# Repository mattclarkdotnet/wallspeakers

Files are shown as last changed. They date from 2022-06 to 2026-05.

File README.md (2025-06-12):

# wallspeakers

Depth 46mm (as flat as the TV)
Max continuous output 95dB @ >80Hz, 85dB @50Hz (suitable for small room use)
IDD ~ 50mm (minimal lobing at crossover where 1/4 wavelength is ~200mm)
Crossover ~400Hz (avoids BMR distortion below that)
Wide dispersion & low IDD mean even tonality vertically and horizontally for wide or no sweet spot

## construction

The interior depth is set to be exactly the mounting depth of the bass driver less the thickness of the rebate, so the magnet would just touch the back wall if there was no gasket between the driver flange and the rebate.  When mounting, apply a layer of gasket material to the rear of the bass driver as well as to the rebate.

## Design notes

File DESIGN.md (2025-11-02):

The world’s slimmest and most advanced on-wall loudspeaker.
- [ ] Just 50mm deep for discreet wall mounting
- [ ] Sleek design to match all rooms
- [ ] Machined from aluminium for ultimate strength and sound quality in a small package
- [ ] Direct driver control with room correction and listening position optimisation
- [ ] Accurate sound anywhere in the room
- [ ] Suitable as a centre speaker or a stereo pair or both
- [ ] Stereo audio from TV (analog or digital)
- [ ] App for control and customisation
- [ ] IR learning of TV volume
- [ ] Matching control box and remote
- [ ] Expandable with extra speakers and subwoofers
- [ ] Optional grille
- [ ] Custom colours

For later designs:
- [ ] HDMI ARC/eARC audio input
- [ ] HDMI control of volume

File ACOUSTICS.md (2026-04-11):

* 2 x Dayton LW150-4 woofers (86dB/2.83V, Re=3.6, parallel Re=1.8)
* 1 x Tectonic TEBM28C10 (80dB/2.83V, Re=3.9)
* 500x200x48mm aluminium cabinet
* 400Hz crossover

### Driver sensitivity matching

The two woofers have a combined sensitivity (being closely spaced and seeing the same signal) of 86+6=92dB/2.83V, at the cost of a reduced Re of 1.8.

Therefore at the crossover frequency the woofer level needs to be reduced by 12dBSPL, or 24dBV

However a Linkwitz Transform is applied to the woofer, which has a 10dBV gain.  We will likely also want to apply up to 10dB of loudness compensation and/or room correction for low level listening to the bass region.  Therefore the 24dBV drop at the crossover region will work out well to provide the needed bass headroom.

### Driver power handling

The woofers have a Linkwitz transform applied to move f3 to 54Hz and f6 to 42Hz.

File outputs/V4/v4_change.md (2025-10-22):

* change total depth to 48mm (proto 1 was designed to be 50mm but ended at 43mm due to machining issue)
* increased the rim lip depth from 5 to 5.5mm to allow for use of glued-on 0.8mm rubber gasket material on back plate
* increased from 3 to 4 screw posts per side, with nominal 14mm post diameter
* moved the BMR driver 5mm inboard (so hole centre is now 45mm from midline, down from 50mm before)
* added machined subenclosure woth optimised shape to address resonance issues
* combined the machined subenclosure and its screw posts
* Reduced woofer support ring diameter (168->160)
* increased BMR support ring diameter (65->66)
* removed dress-up detail on the main shell interior that wasn't structural
  * kept the fillet around the edges to match the exterior roundover, as this is structurally important
  * left all other fillets and chamfers on the interior to  the machinists discretion

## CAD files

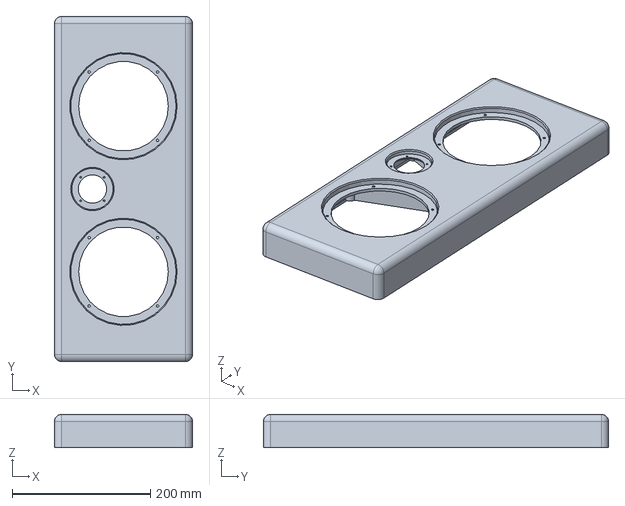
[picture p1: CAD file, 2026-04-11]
cad_models/wallspeakers prototype v5-main shell.step
200.0 x 500.0 x 48.0 mm

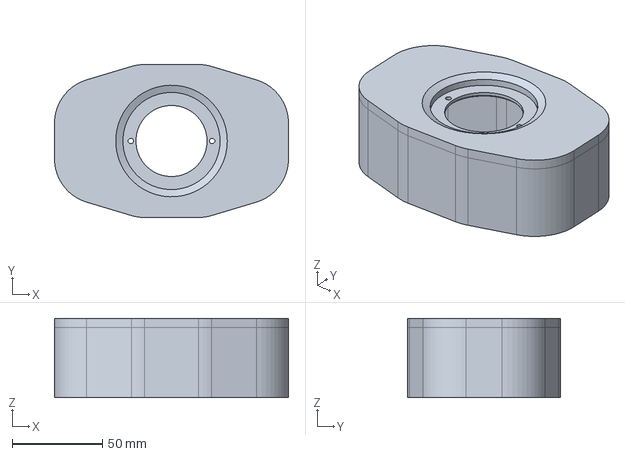
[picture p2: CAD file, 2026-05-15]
cad_models/mule v8.0.FCStd
130.0 x 85.0 x 44.1 mm

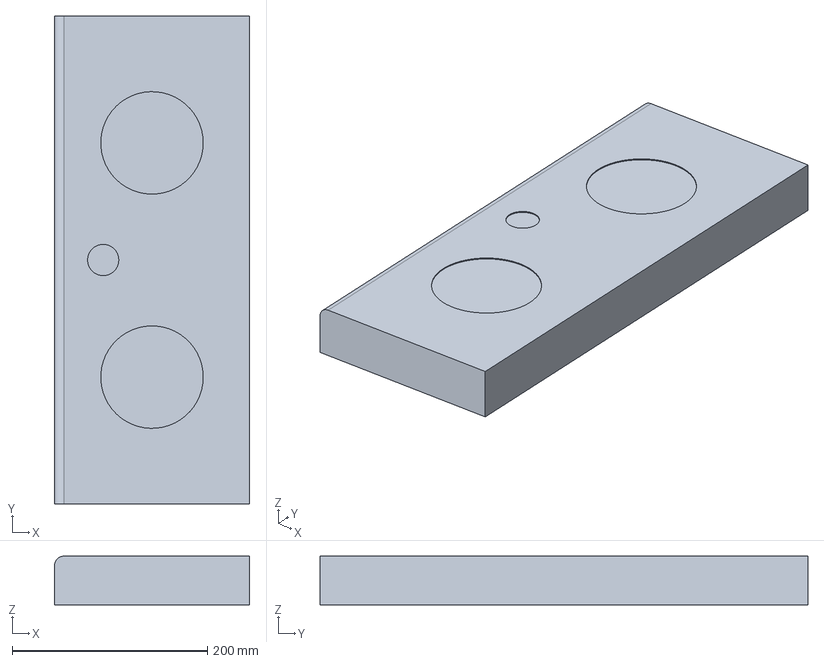
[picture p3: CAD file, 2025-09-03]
sim/enclosure model.FCStd
200.0 x 500.0 x 50.0 mm

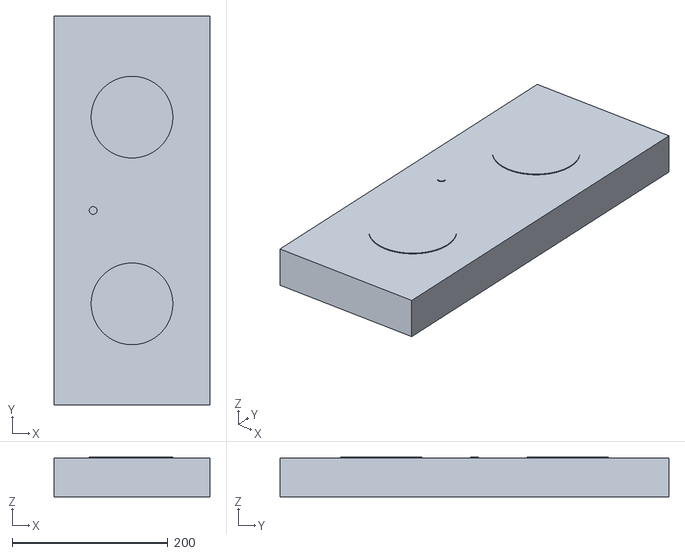
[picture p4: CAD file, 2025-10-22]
sim/meshes/hard_small.stl
200.0 x 500.0 x 51.0

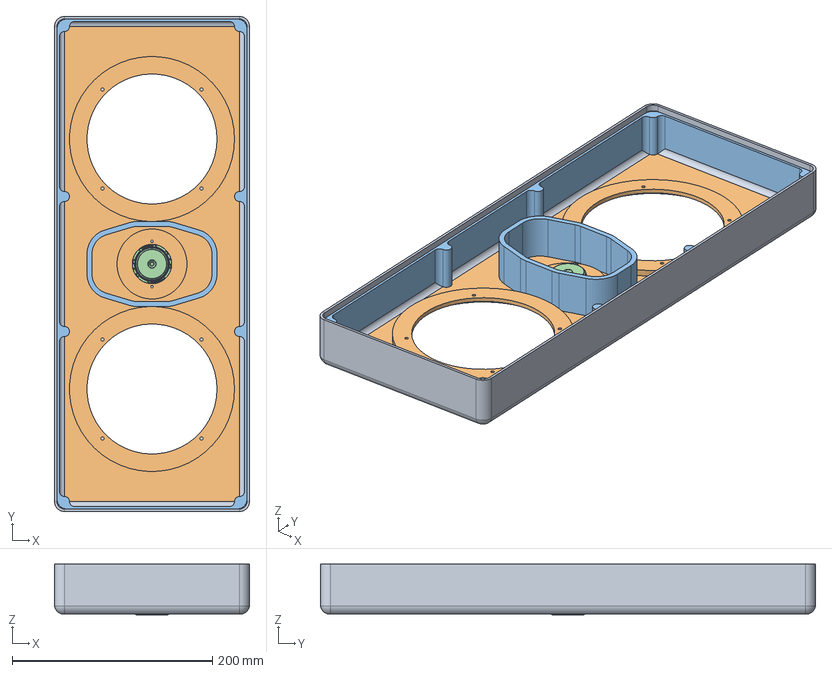
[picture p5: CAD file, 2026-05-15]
cad_models/wallspeakers prototype v8.0.FCStd
195.0 x 495.0 x 50.6 mm
walls
front
screw posts
BMR27C-8A

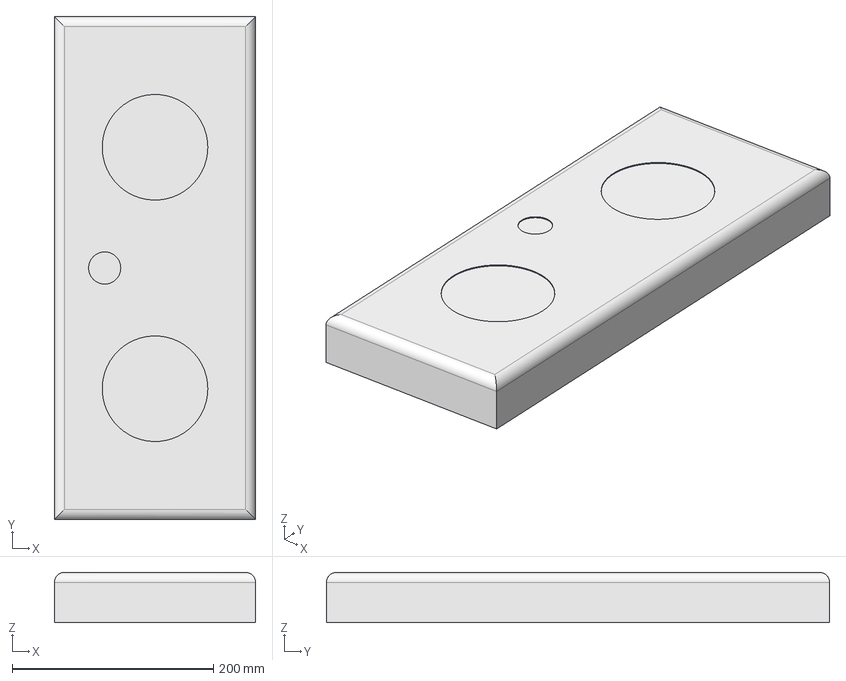
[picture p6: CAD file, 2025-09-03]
sim/meshes/roundovers.step
200.0 x 500.0 x 50.0 mm

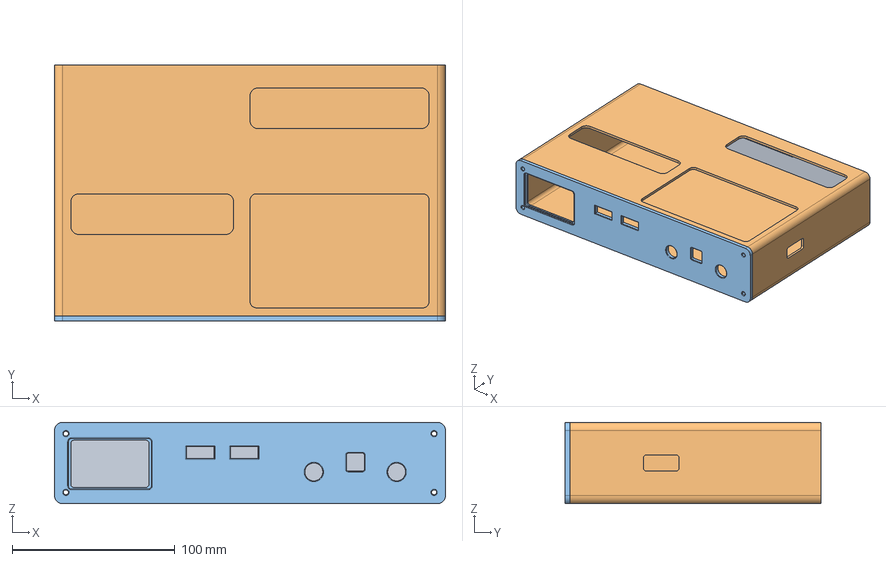
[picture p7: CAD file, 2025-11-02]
cad_models/housing v0.1.FCStd
240.0 x 157.0 x 50.0 mm
front panel
rear panel

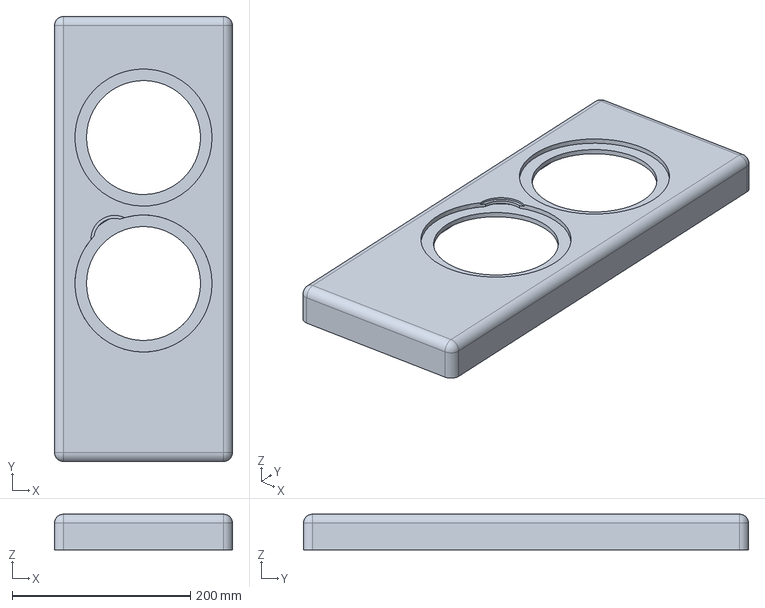
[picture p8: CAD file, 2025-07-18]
cad_models/wallspeakers aluminium prototype.FCStd
200.0 x 500.0 x 40.0 mm

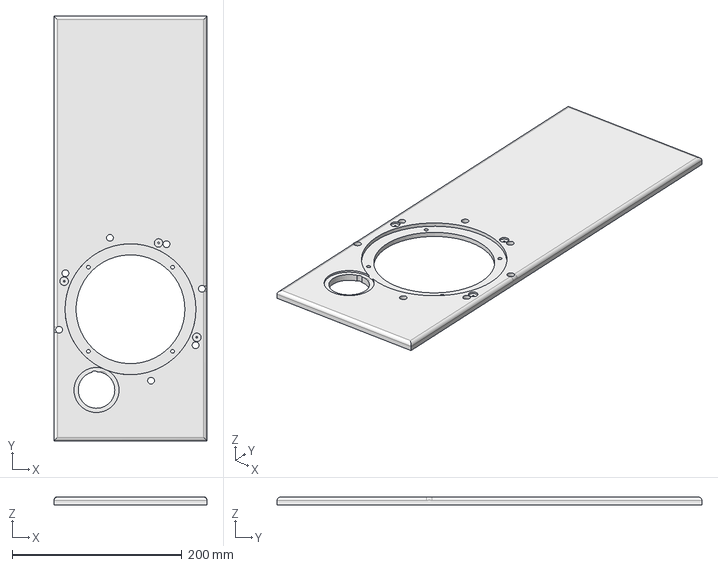
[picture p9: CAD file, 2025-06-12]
cad_models/baffle.FCStd
180.0 x 500.0 x 9.00 mm

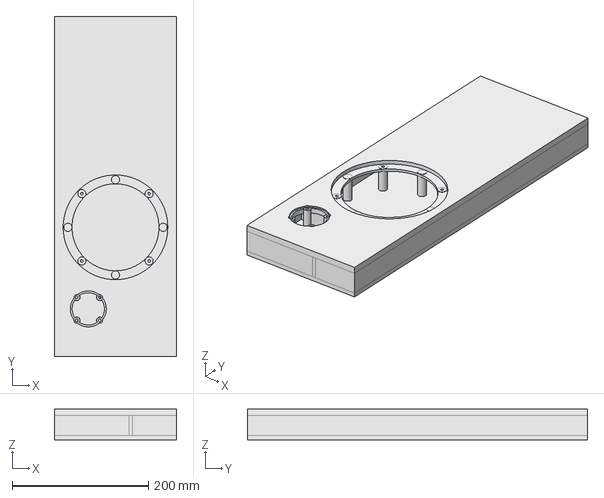
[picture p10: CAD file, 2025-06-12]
cad_models/baffle3.FCStd
180.0 x 500.0 x 45.0 mm

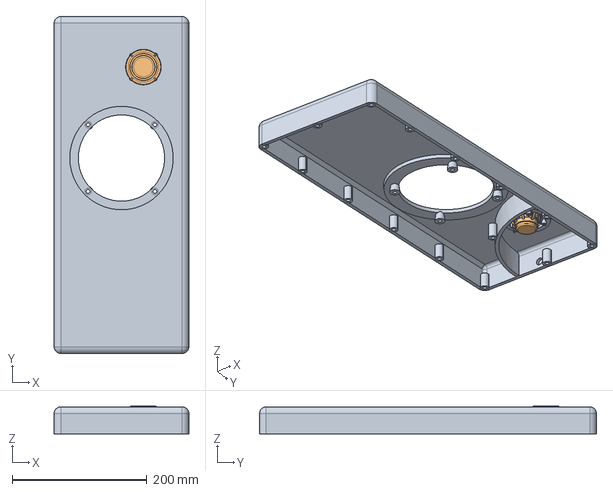
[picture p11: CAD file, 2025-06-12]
cad_models/wallspeakers 0.1.FCStd
200.0 x 500.0 x 41.0 mm
front part
2in BMR driver

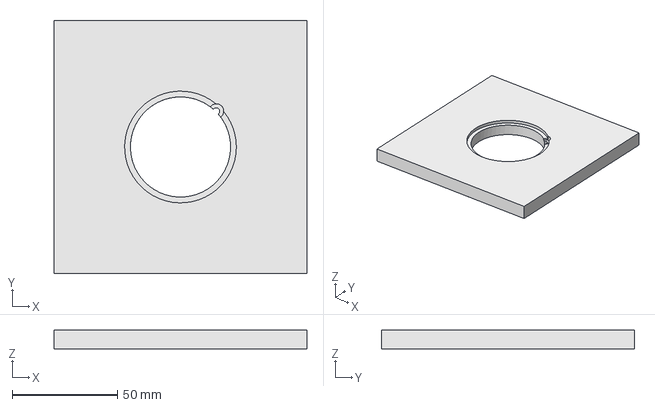
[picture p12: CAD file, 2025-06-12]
cad_models/baffle3 - testpart.FCStd
120.0 x 120.0 x 9.00 mm

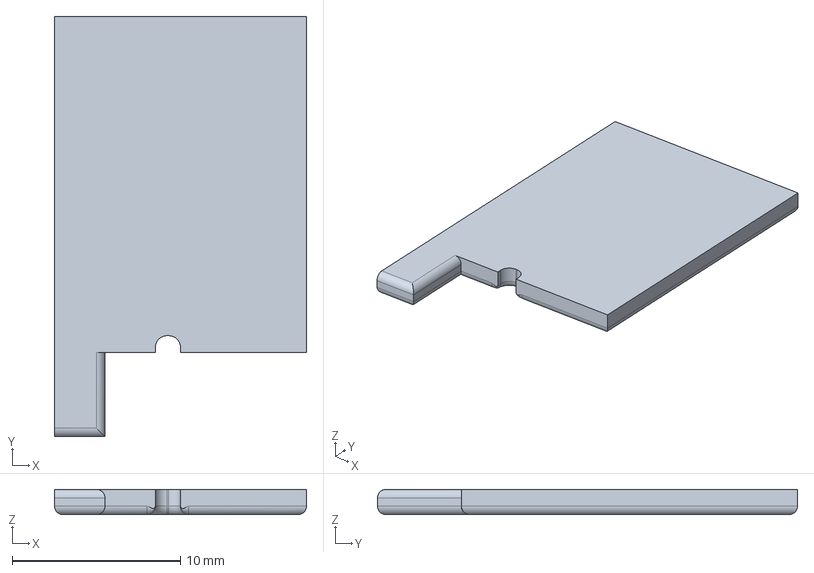
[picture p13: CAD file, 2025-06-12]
cad_models/applicator.FCStd
15.0 x 25.0 x 1.50 mm

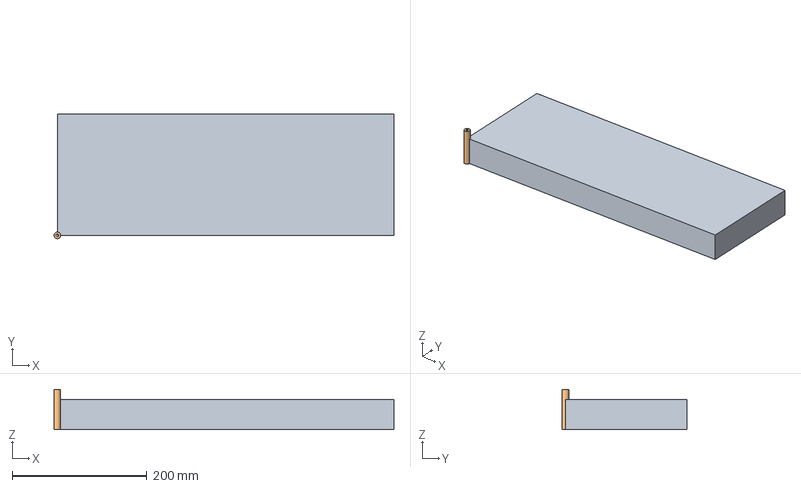
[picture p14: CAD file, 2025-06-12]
cad_models/baffle4.FCStd
505.0 x 185.0 x 60.0 mm
Tube

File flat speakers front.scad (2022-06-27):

$fa = 1;
$fs = 0.01;

include <drivers.scad>
fp_thickness=9;
fp_width=180;
fp_height=500;
fp_roundover=4;

bmr_driver_x_offset = -fp_width/2+50;
bmr_driver_y_offset = -fp_height/2+70;
bass_driver_x_offset=0;
bass_driver_y_offset=-fp_height/2+190;

rebate=fp_thickness/2;
interior_depth=(bass_driver_total_depth-bass_driver_rebate_depth)-(fp_thickness-bass_driver_rebate_depth);
//interior_depth=32; // the driver only needs 28mm, but then the box volume is a bit smaller
echo(str("interior_depth(mm) = ", interior_depth));
echo(str("volume(l) = ", interior_depth*(fp_height-bp_thickness*2)*(fp_width-sp_thickness*2)/1000000));

bp_thickness = 9;
bp_width = fp_width;
bp_height = interior_depth + rebate*2;

sp_thickness = 9;
sp_width = fp_height - rebate*2;
sp_height = interior_depth + rebate*2;


module faceplate_body() {
    difference() {
        cuboid([fp_width,fp_height,fp_thickness], rounding=fp_roundover,
            edges=[TOP+FRONT,TOP+RIGHT,TOP+LEFT,TOP+BACK]);
        translate([0, 0, -(fp_thickness-rebate)])
            rect_tube(size=[fp_width+$fs,fp_height+$fs], h=rebate+$fs, wall=rebate+$fs);
    }
}

module rebated_panel(w,h,d,height,wall) {
    difference() {
        translate([0, 0, d/2])
            cuboid([w-$fs, h-$fs, d-$fs]);
        translate([0, 0, -$fs])
            rect_tube(size=[w+$fs, h+$fs], h=height+$fs, wall=wall+$fs);
    }

}

// Front panel
color("Turquoise")
difference() {
    faceplate_body();
    translate([0, bass_driver_y_offset, 0])
        LW150(fp_thickness);
    translate([bmr_driver_x_offset, bmr_driver_y_offset, 0])
        TEBM35C10(fp_thickness);        
}

// Bottom/top panel 1 (bottom)
color("Green")
    translate([0,-fp_height/2+bp_thickness,-bp_height/2])
        rotate([90,0,0])
            rebated_panel(bp_width, bp_height, bp_thickness, rebate, rebate);

// Bottom/top panel 2 (top)
color("Green")
    translate([0,fp_height/2-bp_thickness,-bp_height/2  ])
        rotate([90,0,180])
            rebated_panel(bp_width, bp_height, bp_thickness, rebate, rebate);

// Side panel 1 (right)
color("Yellow")
    translate([fp_width/2-sp_thickness, 0, -sp_height/2])
        rotate([90,0,90])
            rebated_panel(sp_width, sp_height, sp_thickness, rebate, rebate);

// Side panel 2 (left)
color("Yellow")
    translate([-fp_width/2+sp_thickness, 0, -sp_height/2])
        rotate([90,0,-90])
            rebated_panel(sp_width, sp_height, sp_thickness, rebate, rebate);

// Interior panel 1
ipw1=fp_width/2-sp_thickness/2;
color("Grey")
    translate([-ipw1/2+sp_thickness/2, -140, -sp_height/2])
        rotate([90,0,0])
            cuboid([ipw1, interior_depth, fp_thickness]);

// Interior panel 2
ipw2=(fp_height/2-140)-fp_thickness-fp_thickness/2;
color("Grey")
    translate([0, -fp_height/2+ipw2/2+bp_thickness, -sp_height/2])
        rotate([90,0,90])
            cuboid([ipw2, interior_depth, fp_thickness]);

// Interior brace
color("Grey")
    translate([0, fp_height/2-140, -sp_height/2])
        rotate([90,0,90])
            difference() {
                cuboid([interior_depth*3+5, interior_depth, fp_thickness]);
                xcopies(interior_depth, n=3)
                    cyl(d=interior_depth-5,l=fp_thickness+$fs);
            }



// Back panel (same as front panel without driver cutouts)
// color("Pink")
//     translate([0,0,-(sp_height-rebate)])
//         rotate([180,0,0])
//             rebated_panel(fp_width, fp_height, fp_thickness, rebate, rebate);

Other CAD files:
sim/meshes/bmr_edge.step
sim/meshes/hard.step
cad_models/speaker v5.FCStd
cad_models/wallspeakers v0.1.FCStd
cad_models/baffle2.FCStd
cad_models/wallspeakers prototype v2.FCStd
cad_models/wallspeakers prototype v3.FCStd
cad_models/wallspeakers prototype v4.FCStd
cad_models/wallspeakers prototype v5.FCStd
cad_models/wallspeakers prototype v6.1.FCStd
cad_models/wallspeakers prototype v6.2.FCStd
cad_models/wallspeakers prototype v6.FCStd
cad_models/wallspeakers prototype v7.0.FCStd
cad_models/wallspeakers prototype v7.1.FCStd

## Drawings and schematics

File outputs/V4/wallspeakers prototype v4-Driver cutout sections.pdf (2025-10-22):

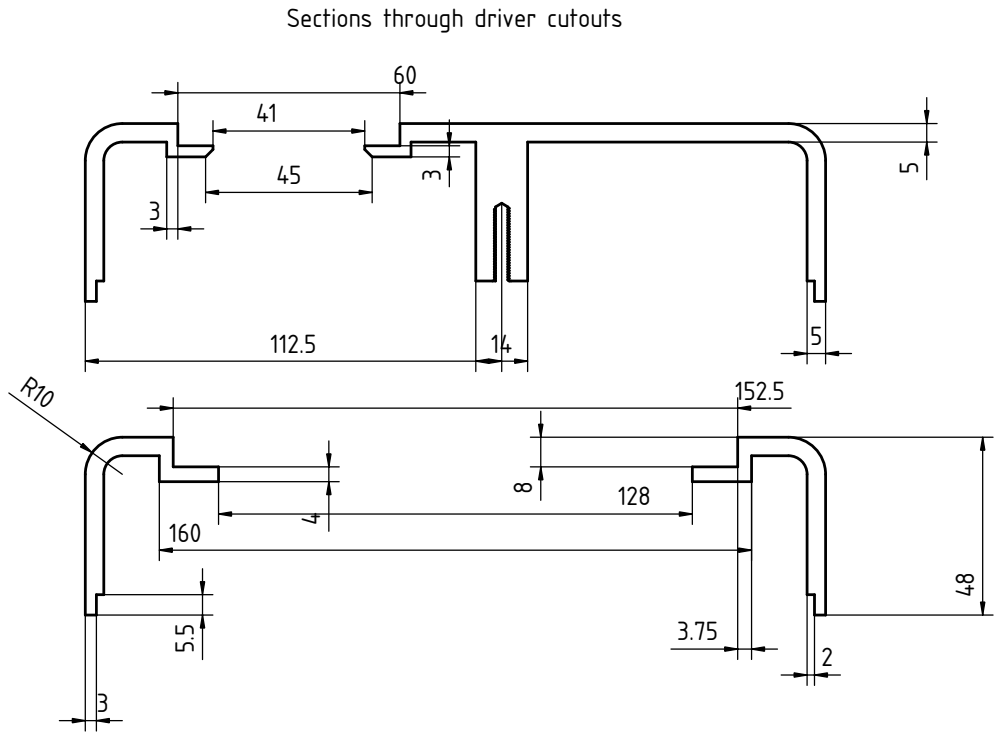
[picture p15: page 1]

Sections through driver cutouts

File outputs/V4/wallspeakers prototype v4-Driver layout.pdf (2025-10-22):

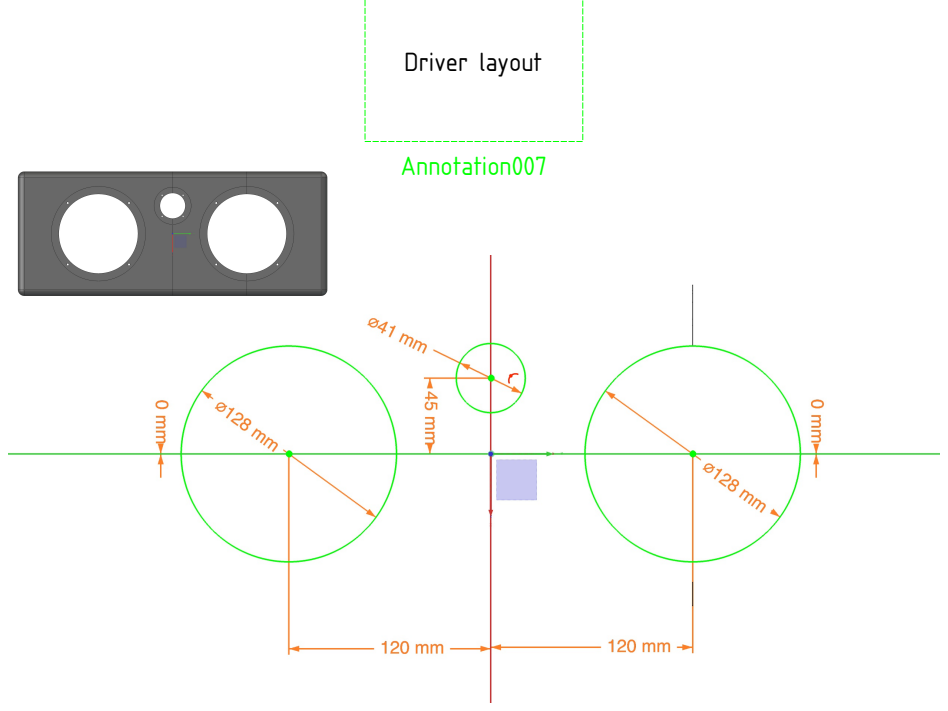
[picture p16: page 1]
Driver layout

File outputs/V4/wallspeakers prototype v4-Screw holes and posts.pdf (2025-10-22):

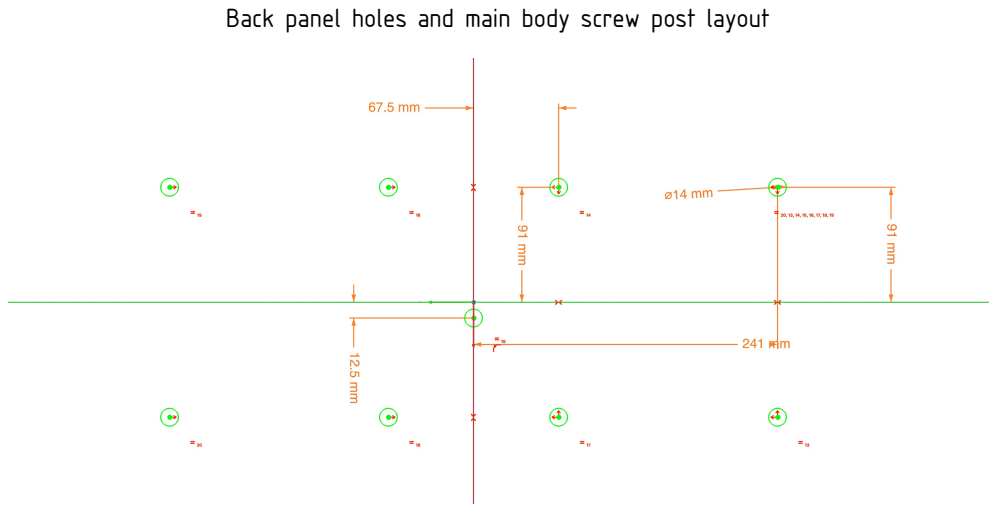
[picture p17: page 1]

Back panel holes and main body screw post layout

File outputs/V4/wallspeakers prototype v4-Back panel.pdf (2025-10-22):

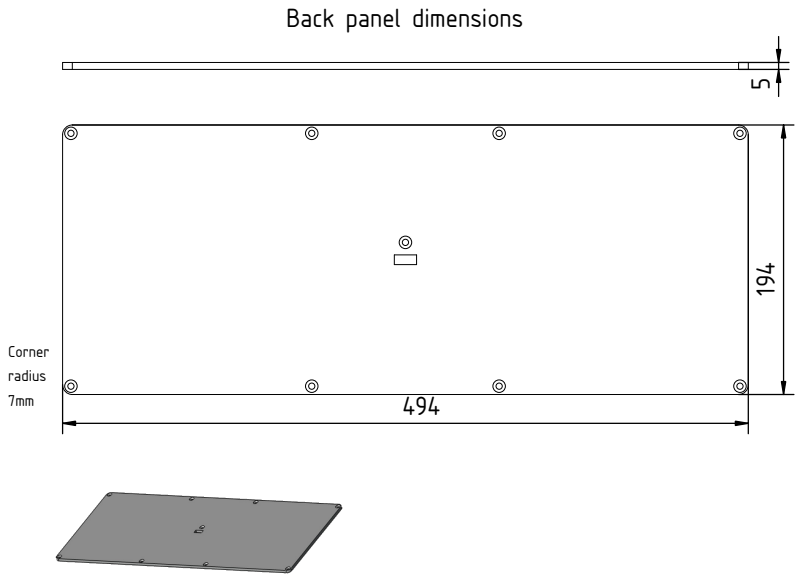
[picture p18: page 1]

Back panel dimensions

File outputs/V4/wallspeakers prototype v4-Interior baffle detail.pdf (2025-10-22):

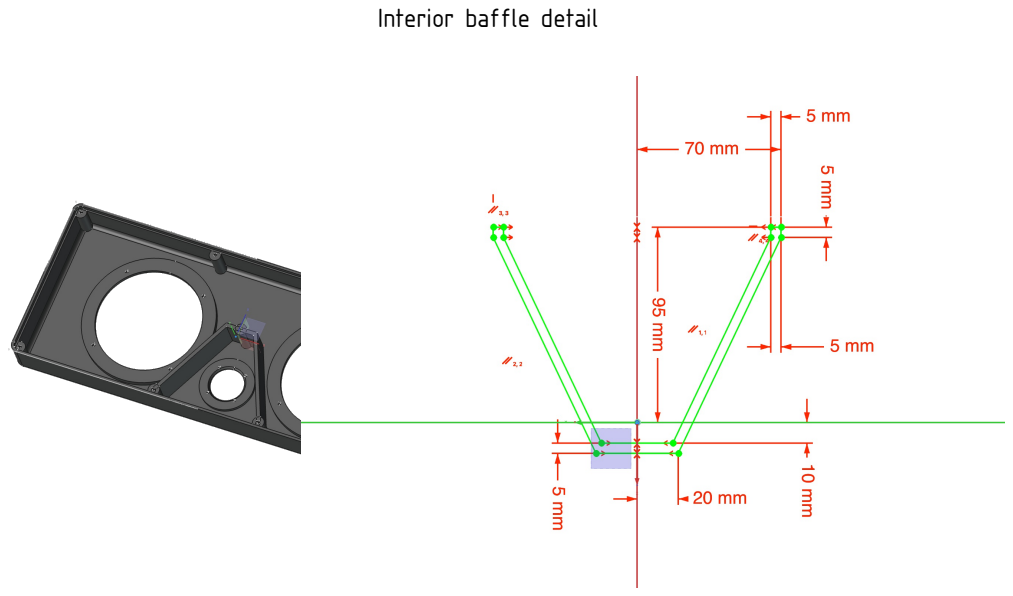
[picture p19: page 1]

Interior baffle detail

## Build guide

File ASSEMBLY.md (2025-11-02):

* Inspect cabinet and back panel on handover from machine shop
 * Dimensions
 * Hole locations
 * Back plate fit
 * Finish quality (evenness, burrs, nicks)

* Attachment of CLD layer
  * Prepare back panel for gluing by scuffing the interior face with 400 grit sandpaper then wiping with IPA
  * Cut 520x220mm section of 0.8mm nitrile rubber and clean one face with IPA
  * Spray both faces to be glued with kwik-grip
  * Wait 2 minutes to allow to get tacky
  * place rubber on work surface glued face up
  * place backplate on rubber glued face down
  * apply light pressure for 1 minute

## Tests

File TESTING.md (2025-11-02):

# How to test an assembled prototype unit

## Indoors / small signal

### LF impedance

### HF impedance

### nearfield LF

### nearfield HF

### Cabinet vibration

### Sensitivity at Fxo for each driver

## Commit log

2022-06-11 added existing files
    [flat speakers front.scad]
2022-06-21 Factored out BMR drivers
    [flat speakers front.scad]
2022-06-21 Added BMR file
    [TEBM35C10.scad]
2022-06-22 Move more driver specifics into drivers.scad
    [TEBM35C10.scad, drivers.scad, flat speakers front.scad]
2022-06-24 completed panels; simplified translations
    [drivers.scad]
2022-06-24 simplified panel translations
    [flat speakers front.scad]
2022-06-27 Finalising before drawing
    [drivers.scad, flat speakers front.scad]
2022-06-29 remeasured bass driver, removed chamfer
    [drivers.scad, flat speakers.scad]
2022-06-29 rechecked screwhole sizes - assume M4 and M2 bolts
    [drivers.scad]
2022-06-29 Triple checked all dimensions
    [drivers.scad, flat speakers.scad]
2022-06-29 Tidied up drivers code, finalised interior depth
    [flat speakers.scad]
2022-06-29 Finalised interior depth
    [drivers.scad]
2025-06-12 added all FCStd files
    [applicator.FCStd, baffle.FCStd, baffle2.FCStd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]
2025-07-18 added alu design
    [wallspeakers aluminium prototype.FCStd]
2025-08-31 starting ElectroacPy sim
    [enclosure model.FCStd, roundovers.stl, sharp.stl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]
2025-09-01 use study IDs
    [enclosure model.FCStd]
2025-09-01 add step files
    [enclosure model.FCStd, hard.step, roundovers.step]
2025-09-02 settled on 3 models and their face configs
    [bmr_edge.step, enclosure model.FCStd]
2025-09-03 addedd meshes
    [bmr_edge.step, enclosure model.FCStd, hard.step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]
2025-10-22 tidying up
    [hard_small.stl, wallspeakers prototype v4.FCStd]
2025-10-22 more tidying up
    [applicator.FCStd, baffle.FCStd, baffle2.FCStd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]
2025-10-22 further tidying
    [applicator.FCStd, baffle.FCStd, baffle2.FCStd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]
2025-10-22 neating up
    [flat speakers.scad]
2025-11-02 More tidying
    [drivers.scad, housing v0.1.FCStd]
2026-04-11 various model updates
    [backplate.kicad_pcb, backplate.kicad_sch, bom.csv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]
2026-05-15 added new cad files
    [mule v8.0.FCStd, wallspeakers prototype v7.0.FCStd, wallspeakers prototype v7.1.FCStd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]
